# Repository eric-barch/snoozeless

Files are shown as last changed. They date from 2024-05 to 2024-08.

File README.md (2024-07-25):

# Snoozeless

Make yourself a morning person.

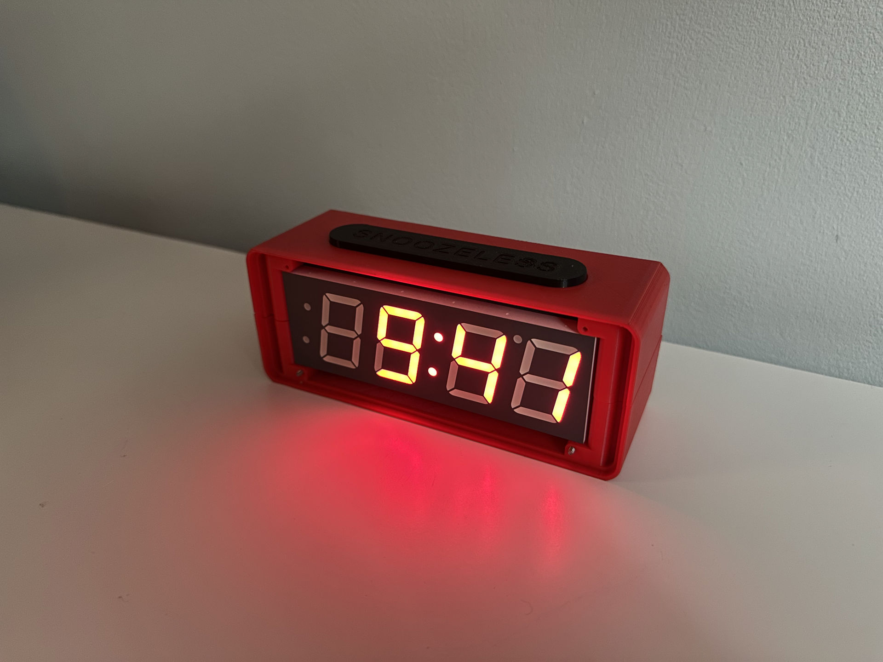
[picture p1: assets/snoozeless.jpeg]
The Snoozeless Alarm Clock


## The Problem

I’m a night owl by nature. Whether it’s genetic or a habit picked up in school, I’ve always had a tendency to wake up around 8 or 9 and fall asleep around 1 or 2.

On the rare occasion that I do wake up early (like, 6 or earlier), I always have a fantastic day. I've usually exercised, made breakfast, and gotten some work done by the time others are waking up. I feel like I have a head start on everyone else, setting the tone for a productive day.

Once I'm awake, I feel great, but the challenge is getting to that point. My discipline is at its absolute lowest at the moment my alarm sounds. No matter how good my intentions were when I set it the night before, and despite knowing logically that getting up is the right decision, I usually end up hitting snooze. And then hitting it again. And again. An embarassing number of 9-minute increments later, I finally get up around the time that I would have naturally, having accomplished nothing by setting an alarm other than decreasing the quality of my last hour of sleep.

I needed a way to change the incentives at the critical moment of decision, to make it more immediately expensive to stay in bed than to leave it.

## The Solution

The solution I landed on is an alarm clock that goes off not once, but twice. The first alarm functions like any regular alarm — it goes off, you wake up, and you turn it off. Turning off the first alarm, however, triggers a countdown to a second. The key difference is that the only way to cancel the countdown (or turn off the second alarm, if you've run out of time) is to physically reach a pre-determined geographic location (the gym, work, class, etc.). This design changes your incentives while you’re contemplating whether to get up. With the countdown ticking, every minute spent in bed reduces the time you have to reach your destination. You know that if the countdown reaches zero, the alarm will go off and you won’t be able to stop it.

Initially, I thought this could be a simple mobile app, but it’s actually impossible to implement on a device over which you don’t have full control of the hardware. If the alarm is going off on your phone, it can be turned off by simply quitting the app. This solution, then, requires a :sparkles:_distributed system_:sparkles:: an embedded device with full control over its noise-making peripherals to serve as the alarm clock, and a mobile app to confirm that you've reached your target location.

## Couldn't You Just...

### Unplug it?

No. There's a battery inside that's charging whenever it's plugged in. It can run for hours without wall power.

### Throw it across the room/move it to a different one?

No. There are screw holes under the snooze(less) bar that allow you to anchor the clock to something solid (e.g. your nightstand) if you really need to.

### Disconnect the internet?

No. Once the wakeup cycle begins, all logic runs onboard. All you accomplish by cutting the internet is to make it impossible to tell Snoozeless you've reached your destination. The second alarm will sound as scheduled until internet is restored and you've reached your destination.

### Turn it off via the server?

No. When the mobile app tells the server that you've reached your destination, it signs that message with a private key. Snoozeless validates the message with the corresponding public key. Even for me, with full access to the application's backend, it's cryptographically impossible to turn off an alarm by any method other than getting my phone to the correct geographic coordinates.

### Smash it with a hammer?

Yes. Yes, you could smash it with a hammer. I've put so much work into Snoozeless that I don't think some extra sleep would ever be worth that to me. If the tradeoff is different for you, the CAD files are [here](cad); I suggest machining it from steel.

## The Implementation

The pieces of the system are as follows:

### Database

Stores application state. Built with [Supabase](https://supabase.com/). There are only two tables, `devices` and `alarms`, plus the tables that Supabase generates automatically for auth and other concerns.

### Server

Handles routing and backend logic. Pre- and post-processes most of the database reads and writes. Implemented with [Hono](https://hono.dev/), which is pretty much just a modern, lightweight, TypeScript-first alternative to [Express](https://expressjs.com/). I've really enjoyed using it. Currently I just run the server locally on my machine, but plan to deploy it to the cloud in a Docker container running Node.

### Mobile Application

The need to know the user's location requires a mobile app. This one is built with [Flutter](https://flutter.dev/) and thus written in [Dart](https://dart.dev/).

### Embedded Application

Lastly, a standalone device needs a board and firmware. The [ESP32](https://www.espressif.com/en/products/socs/esp32) by Espressif is a very popular System on a Chip for Internet of Things applications. I have some experience programming these using the [Arduino](https://www.arduino.cc/) framework, but for this project I chose to use Espressif's own [ESP-IDF](https://github.com/espressif/esp-idf) for its lower-level control (and just to learn something new). The ESP-IDF libraries are written in C but fully support C++, which I took advantage of due to my proclivity for and/or addiction to object-oriented programming.

## Build One

I'm putting together a full build guide, but it's still a work in progress. Unfortunately, if you want to make your own, you're going to have to reverse engineer it from the resources in this repo. The CAD files are designed around these components from Adafruit:

- [Adafruit ESP32 Feather V2 - 8MB Flash + 2 MB PSRAM - STEMMA QT](https://www.adafruit.com/product/5400)
- [Breadboard-friendly 2.1mm DC barrel jack](https://www.adafruit.com/product/373)
- [Tactile Button switch (6mm) x 20 pack](https://www.adafruit.com/product/367)
- [Large Enclosed Piezo Element w/Wires](https://www.adafruit.com/product/1739)
- [Adafruit 7-Segment Backpack - 1.2" Tall Digits](https://www.adafruit.com/product/1271)
- [Red 7-segment clock display - 1.2" digit](https://www.adafruit.com/product/1264)

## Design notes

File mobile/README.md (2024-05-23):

# Snoozeless

Mobile app for the alarm clock that forces you to get out of bed in the morning.

## Use Case

Have you always wanted to be a morning person, but never been able to make it happen? What if your alarm clock absolutely **refused** to turn off until you got your lazy butt out of bed? Snoozeless _wakes_ you up like a normal alarm clock, but then forces you to actually _get_ up by threatening a second alarm if you don't physically move to a certain location within a time limit. A mobile app alone can't accomplish the task -- you could always override the alarm by simply quitting the app or turning off your phone. The product _needs_ to be a physical device with full control over its own audio output.

Snoozeless is a physical alarm clock accompanied by a mobile app. The clock is built around the [ESP32 System on a Chip](https://www.espressif.com/en/products/socs/esp32) and has a built-in rechargeable battery so you can't turn off the alarm by unplugging it.

## Setup

**Note:** The below is how Snoozeless used to work. It was never a commercial product, just something I used myself. The project is no longer developed or maintained.

1. Flash an ESP32 with the firmware and attach the necessary peripherals. Put it all in an enclosure. More detail at the [firmware repo](https://github.com/eric-barch/snoozeless-firmware).
2. Download the Snoozeless app, or clone this repo and install the app on your phone from your computer.
3. Create or sign in to an account in the app.
4. Pair the clock to your phone via Bluetooth.

## Daily Use

1. Before going to bed, open the app and configure the following settings for your clock:

- The time you want to be woken up initially
- The geographic destination you want to be forced to go to
- The amount of time you want to be given to get there

2. In the morning, you will be woken up at the initial time you set in step 1. You can turn off this first alarm by pressing the snooze bar on top of the clock.
3. Completing step 2 will start a countdown of the duration you set in step 1.
4. Bring your phone to the geographic location you set in step 1. Once your phone is close enough to the location, the countdown on your physical alarm clock will cancel. If the countdown has already elapsed and the alarm is sounding, it will turn off.
5. If you fail to get to your destination by the time the countdown ends, the second alarm will sound. There is no way to turn this alarm off other than by getting to the place you set in step 1. So hurry up! Get to work/gym/class/wherever!

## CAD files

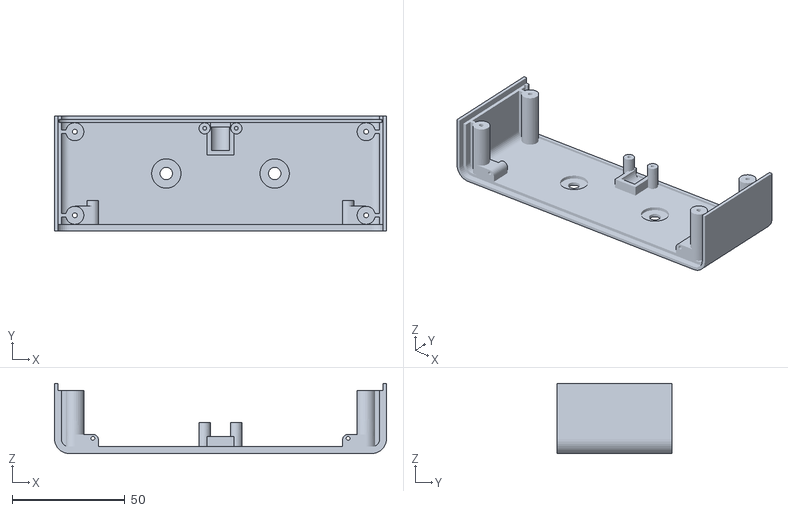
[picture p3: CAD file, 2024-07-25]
cad/snoozeless-bottom.stl
147.0 x 51.0 x 31.0

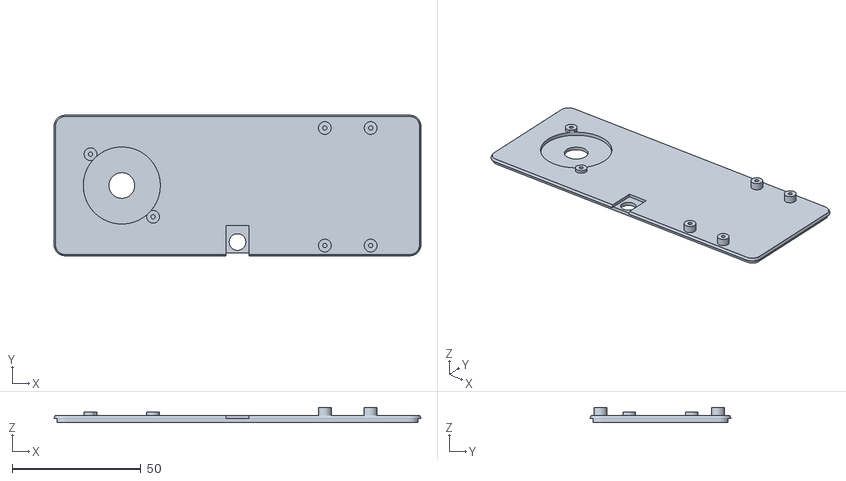
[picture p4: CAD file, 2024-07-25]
cad/snoozeless-back.stl
142.8 x 54.8 x 5.80

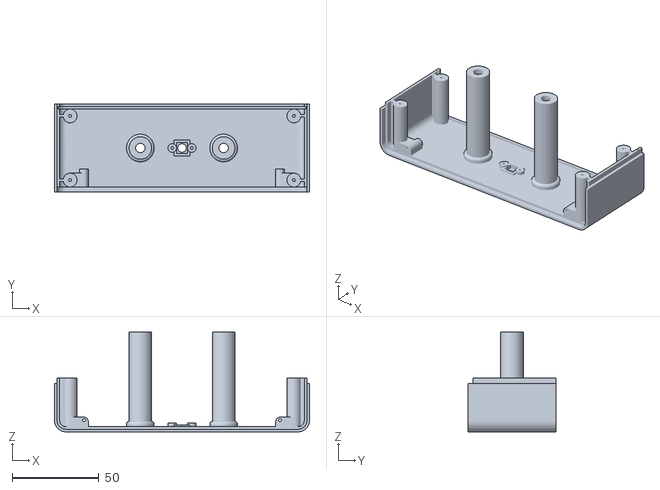
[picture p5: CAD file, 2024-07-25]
cad/snoozeless-top.stl
147.0 x 51.0 x 57.5

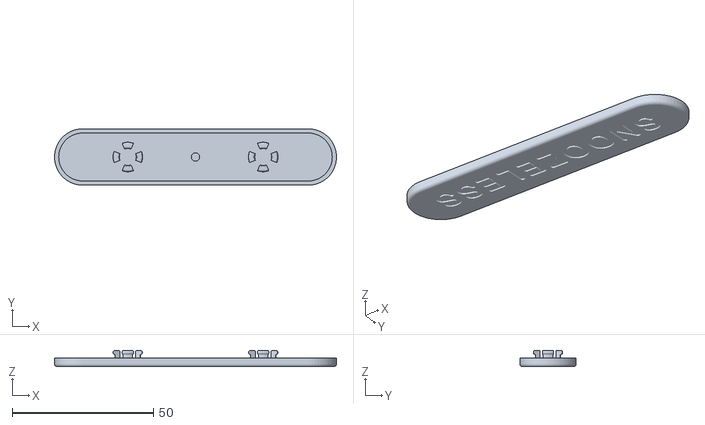
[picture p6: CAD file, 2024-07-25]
cad/snoozeless-bar.stl
100.0 x 20.0 x 5.81

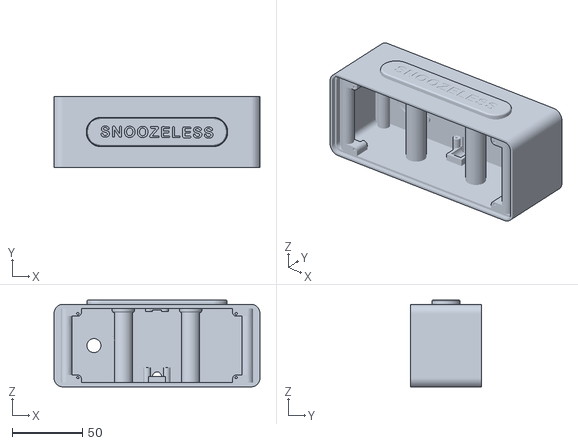
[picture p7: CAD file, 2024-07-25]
cad/snoozeless.stl
147.0 x 51.0 x 62.0

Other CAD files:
cad/snoozeless.f3d

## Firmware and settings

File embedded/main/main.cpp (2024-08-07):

#include "Alarms.h"
#include "Button.h"
#include "Buzzer.h"
#include "CurrentTime.h"
#include "Device.h"
#include "Display.h"
#include "NonVolatileStorage.h"
#include "Session.h"
#include "StateMachine.h"
#include "StateStream.h"
#include "WifiConnection.h"
#include <freertos/idf_additions.h>

extern "C" void app_main(void) {
  /**ESP system utilities. */
  NonVolatileStorage non_volatile_storage;
  WifiConnection wifi_connection(non_volatile_storage);

  /**Auth. */
  Session session(non_volatile_storage);

  /**State. */
  Device device(non_volatile_storage);
  Alarms alarms(non_volatile_storage);

  /**Realtime state updates from backend. */
  StateStream state_stream(session, device, alarms);

  /**UNIX time. */
  CurrentTime current_time(non_volatile_storage, session);

  /**Peripherals. */
  Button button;
  Buzzer buzzer;
  Display display(device, current_time);

  /**Orchestrate processes. */
  StateMachine state_machine(device, alarms, current_time, button, display,
                             buzzer);

  vTaskDelay(portMAX_DELAY);
}

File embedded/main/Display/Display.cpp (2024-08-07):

#include "Display.h"
#include "CurrentTime.h"
#include "Device.h"
#include "NonVolatileStorage.h"
#include <cstring>
#include <ctime>
#include <esp_log.h>
#include <freertos/idf_additions.h>
#include <ht16k33.h>
#include <i2cdev.h>
#include <regex>
#include <string>

Display::Display(Device &device, CurrentTime &current_time)
    : device(device), current_time(current_time), ht16k33(), ht16k33_ram(0),
      top_indicator(false), bottom_indicator(false), colon(false),
      apostrophe(false), major_interval(), minor_interval() {
  /**Initialize display structs. */
  memset(&ht16k33, 0, sizeof(i2c_dev_t));
  memset(&ht16k33_ram, 0, sizeof(ht16k33_ram));

  /**I2C communication pin definitions. */
  gpio_num_t sda = static_cast<gpio_num_t>(CONFIG_I2C_MASTER_SDA);
  gpio_num_t scl = static_cast<gpio_num_t>(CONFIG_I2C_MASTER_SCL);
  i2c_port_t port = static_cast<i2c_port_t>(0);

  /**Configure GPIO2 (I2C power) and set high.
   * https://learn.adafruit.com/adafruit-esp32-feather-v2/pinouts#stemma-qt-connector-3112257
   */
  gpio_config_t io_conf;
  io_conf.intr_type = GPIO_INTR_DISABLE;
  io_conf.mode = GPIO_MODE_OUTPUT;
  io_conf.pin_bit_mask = (1ULL << GPIO_NUM_2);
  gpio_config(&io_conf);
  gpio_set_level(GPIO_NUM_2, 1);

  /**Initialize I2C and ht16k33 display drivers. */
  ESP_ERROR_CHECK(i2cdev_init());
  ESP_ERROR_CHECK(
      ht16k33_init_desc(&ht16k33, port, sda, scl, HT16K33_DEFAULT_ADDR));
  ESP_ERROR_CHECK(ht16k33_init(&ht16k33));
  ESP_ERROR_CHECK(ht16k33_display_setup(&ht16k33, 1, HTK16K33_F_0HZ));
}

Display::~Display() {
  memset(&ht16k33, 0, sizeof(i2c_dev_t));
  ht16k33_free_desc(&ht16k33);
  ESP_LOGI(TAG, "Destroy.");
}

void Display::print_9_41() {
  set_major_interval(std::string("9"));
  colon = true;
  set_minor_interval(std::string("41"));
  bottom_indicator = false;
  print();
}

void Display::print_current_time() {
  std::string hour_format, minute_format, pm_format;
  std::smatch match;

  const std::regex specifier_regex("%[a-zA-Z]");
  const std::regex colon_regex(":");
  const std::regex pm_regex("%p");

  std::string time_format = device.get_time_format();
  std::tm time = current_time.get_time();

  /**Find hour format specifier. */
  if (std::regex_search(time_format, match, specifier_regex)) {
    hour_format = match.str();
    time_format = match.suffix();
  }

  /**Check for colon. */
  if (std::regex_search(time_format, match, colon_regex)) {
    colon = true;
    time_format = match.suffix();
  } else {
    colon = false;
  }

  /**Find minute format specifier. */
  if (std::regex_search(time_format, match, specifier_regex)) {
    minute_format = match.str();
    time_format = match.suffix();
  }

  /**Check for PM indicator. */
  pm_format.clear();
  if (std::regex_search(time_format, match, pm_regex)) {
    pm_format = match.str();
    time_format = match.suffix();
  }

  char buffer[10];

  /**Set major interval. */
  if (!hour_format.empty()) {
    strftime(buffer, sizeof(buffer), hour_format.c_str(), &time);
    set_major_interval(buffer);
  }

  /**Set minor interval. */
  if (!minute_format.empty()) {
    strftime(buffer, sizeof(buffer), minute_format.c_str(), &time);
    set_minor_interval(buffer);
  }

  /**Set bottom_indicator. */
  if (!pm_format.empty()) {
    strftime(buffer, sizeof(buffer), pm_format.c_str(), &time);
    bottom_indicator = (std::string(buffer) == "PM");
  } else {
    bottom_indicator = false;
  }

  print();
}

void Display::print_countdown(Countdown &countdown) {}

const char *const Display::TAG = "display";

const std::map<const char, const uint8_t> Display::alphabet = {
    {'0', 0x3F}, {'1', 0x06}, {'2', 0x5B}, {'3', 0x4F}, {'4', 0x66},
    {'5', 0x6D}, {'6', 0x7D}, {'7', 0x07}, {'8', 0x7F}, {'9', 0x6F},
    {' ', 0x00}, {'A', 0x77}, {'B', 0x7C}, {'C', 0x39}, {'D', 0x5E},
    {'E', 0x79}, {'F', 0x71}, {'G', 0x3D}, {'H', 0x76}, {'I', 0x30},
    {'J', 0x1E}, {'K', 0x75}, {'L', 0x38}, {'M', 0x15}, {'N', 0x37},
    {'O', 0x3F}, {'P', 0x73}, {'Q', 0x6B}, {'R', 0x33}, {'S', 0x6D},
    {'T', 0x78}, {'U', 0x3E}, {'V', 0x3E}, {'W', 0x2A}, {'X', 0x76},
    {'Y', 0x6E}, {'Z', 0x5B},
};

void Display::set_major_interval(const std::string &major_interval) {
  int length = major_interval.length();
  if (length < 1 || length > 2) {
    ESP_LOGE(TAG,
             "Did not set major interval. Must be one or two characters long.");
    return;
  }
  this->major_interval = major_interval;
}

void Display::set_minor_interval(const std::string &minor_interval) {
  int length = minor_interval.length();
  if (length < 1 || length > 2) {
    ESP_LOGE(TAG,
             "Did not set minor interval. Must be one or two characters long.");
    return;
  }
  this->minor_interval = minor_interval;
}

void Display::set_brightness(uint8_t brightness) {
  uint8_t cmd = 0xE0 | brightness;
  esp_err_t err = i2c_master_write_to_device(I2C_NUM_0, ht16k33.addr, &cmd, 1,
                                             1000 / portTICK_PERIOD_MS);
  if (err != ESP_OK) {
    ESP_LOGE(TAG, "Error setting brightness: %s", esp_err_to_name(err));
  }
}

void Display::print() {
  memset(ht16k33_ram, 0, sizeof(ht16k33_ram));

  set_brightness(device.get_brightness());

  if (major_interval.length() > 0) {
    if (major_interval[1] == '\0') {
      ht16k33_ram[0] = alphabet.at(' ');
      ht16k33_ram[2] = alphabet.at(major_interval[0]);
    } else {
      ht16k33_ram[0] = alphabet.at(major_interval[0]);
      ht16k33_ram[2] = alphabet.at(major_interval[1]);
    }
  }

  if (minor_interval.length() > 0) {
    if (minor_interval[1] == '\0') {
      ht16k33_ram[6] = alphabet.at(' ');
      ht16k33_ram[8] = alphabet.at(minor_interval[0]);
    } else {
      ht16k33_ram[6] = alphabet.at(minor_interval[0]);
      ht16k33_ram[8] = alphabet.at(minor_interval[1]);
    }
  }

  uint8_t indicators = 0b00000;

  /**Indicators are set by these bits:
   * 0b00000
   *   ││││└─ no effect
   *   │││└── colon
   *   ││└─── top_indicator
   *   │└──── bottom_indicator
   *   └───── apostrophe */

  if (apostrophe) {
    indicators += 0b10000;
  }
  if (bottom_indicator) {
    indicators += 0b01000;
  }
  if (top_indicator) {
    indicators += 0b00100;
  }
  if (colon) {
    indicators += 0b00010;
  }

  ht16k33_ram[4] = indicators;

  ESP_ERROR_CHECK(ht16k33_ram_write(&ht16k33, ht16k33_ram));
}

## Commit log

2022-02-26 Finalize first draft of Edit Device form and supporting changes.
2022-02-26 Add Delete Device capability.
2022-02-27 Added Add Device capability.
2022-03-06 Added sortBy createdAt for both devices list and alarms list.
2024-05-31 feat(server): Server sends device state changes as SSE stream
2024-06-01 feat(server): Implement auth on GET /device/state endpoint
2024-06-01 feat(server): Implement register device endpoint
2024-06-02 fix(server): Register device endpoint requires user_id _and_ session_id
2024-06-02 feat(server): Implement unregister device endpoint
2024-06-02 refactor(server): Clarify naming of register device service arguments
2024-06-02 fix(server): Get device state endpoint accepts deviceId argument
2024-06-02 feat(server): Implement update device endpoint
2024-06-07 fix(server): deviceId is passed to get device state endpoint in query rather than body
2024-06-13 feat(embedded): Subscribes to SSE device state stream with auth
2024-06-19 feat(embedded): Device ID is retrieved from global state instead of ESP-IDF config
2024-06-20 refactor(server): Register device endpoint uses Supabase client from auth middleware
2024-06-20 feat(embedded): Register device endpoint JSON response is parsed into device state
2024-06-20 fix(embedded): Subscribe to device service calls get device state controller
2024-06-20 fix(server): Fix device state stream typo
2024-06-20 refactor(server): Remove unregister device endpoint
2024-06-21 feat(embedded): Implement getters and setters for device state properties
2024-06-21 feat(embedded): Parse device state stream and write to onboard state
2024-06-21 refactor(embedded): Refactor device state
2024-06-21 refactor(embedded): Put all device state services in one file
2024-06-21 refactor(embedded): Refactor POST device/register controller
2024-06-23 feat(embedded): Implement device state int setters and getters
2024-06-23 feat(embedded): Initializing device sets device state integers
2024-06-23 feat(embedded): Device state stream updates write to onboard device state ints
2024-06-24 feat: GET device/state sends initial state at beginning of stream
2024-06-24 refactor(embedded): Rename device_t to device_state_t
2024-06-24 fix(embedded): Handle unknown device state event type
2024-06-24 style(embedded): Rename GET device state controller variables
2024-06-25 fix(embedded): Align Unix calibration with ESP log messages
2024-06-29 refactor(embedded): Make calibrate_real_time static
2024-07-03 feat(embedded): Implement Device
2024-07-05 feat(embedded): ApiRequest.call runs as separate thread via freeRTOS
2024-07-05 refactor(embedded): Refactor `Device` to match `Session` style and structure
2024-07-05 style(embedded): Improve Device log messages
2024-07-09 feat(embedded): `Device` calls `ApiRequest` on separate thread
2024-07-09 fix(server): `device/register` returns single JSON object instead of array
2024-07-09 feat(embedded): `Device` sets its `id` on enroll
2024-07-09 feat(embedded): Working preliminary implementation of `CurrentTime`
2024-07-09 refactor(embedded): `Device` takes `CurrentTime` as dependency
2024-07-09 feat(embedded): `CurrentTime` calibrates itself via API on init
2024-07-09 refactor(CurrentTime): Add getters and setters
2024-07-09 refactor(Device): Add setter
2024-07-09 style(server): Fix device route imports
2024-07-09 fix: `/auth/refresh` returns snake case
2024-07-09 feat(embedded): Enrolling `Device` sets `utc_offset` and `format` properties on `CurrentTime`
2024-07-10 fix(embedded): `ApiRequest` event handler prints output buffer on auth error
2024-07-10 feat(embedded): Enrolling `Device` sets `Display.brightness`
2024-07-13 feat(embedded): Display shows current Unix time
2024-07-13 feat(embedded): `CurrentTime` accounts for time zone
2024-07-13 fix(embedded): `Display` gets brightness from NVS on startup
    [Display.cpp]
2024-07-16 fix(embedded): `CurrentTime` blocks itself for synchronous API calls
    [main.cpp]
2024-07-16 fix(embedded): `Device` blocks itself for synchronous API requests
2024-07-16 fix(embedded): Make `Display` compatible with Feather HUZZAH32 v2
    [Display.cpp]
2024-07-16 fix(server): Remove extraneous info from GET device/state response
2024-07-16 feat(embedded): `Device` subscribes to state 🎉
2024-07-16 fix(server): Change `/device/register` endpoint to `/device/enroll`
2024-07-16 refactor(embedded): `Device` subscribes itself to state updates
2024-07-18 feat(embedded): `Session` handles failed refresh
    [main.cpp]
2024-07-18 feat(embedded): `CurrentTime` handles failed calibration
    [main.cpp]
2024-07-18 feat(embedded): `Device` handles failed subscription
    [main.cpp]
2024-07-19 feat(embedded): Preliminary implementation of `Buzzer`
    [Buzzer.cpp, main.cpp]
2024-07-19 feat(server): `/device/state/` SSE stream includes alarm updates
2024-07-21 feat(server): GET `/device/state` endpoint sends alarm updates
2024-07-21 fix(embedded): Remove unnecessary loop in `main`
    [main.cpp]
2024-07-24 fix(embedded): Prevent `Display` power crash on first boot
    [Display.cpp]
2024-07-24 refactor(embedded): `Device` manages all of its members
2024-07-24 fix(embedded): Fix clangd LSP for nvim
    [Buzzer.cpp, Display.cpp]
2024-07-24 fix(embedded): Fix stack overflow in `CurrentTime.keep_calibrated`
2024-07-24 fix(server): GET `/device/state` endpoint sends event label for keep-alive
2024-07-24 feat(server): Implement POST `/device/alarm` endpoint
2024-07-24 feat(embedded): `Device` handles initial alarms
2024-07-24 fix(embedded): `CurrentTime` reads NVS calibration from correct key
2024-07-25 feat(cad): Add CAD files
    [snoozeless-back.stl, snoozeless-bar.stl, snoozeless-bottom.stl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]
2024-07-26 feat(embedded): Implement `Display.print_9_41()`
2024-07-26 feat(embedded): `Alarms` are initialized from NVS and then `Device` SSE stream
2024-07-29 refactor(embedded): Refactor `CurrentTime`
2024-07-29 refactor(embedded): Refactor `Device`
2024-07-29 fix(server): POST `/device/enroll` service endpoint return type is implicit
2024-07-29 refactor(embedded): Reduce duplication in `Device`
2024-07-29 fix(embedded): `CurrentTime` properties get default values
2024-07-29 fix(embedded): Add various error guards to `Display`
    [Display.cpp]
2024-07-30 fix(embedded): Fix `Display` crash on initial startup
    [Display.cpp]
2024-07-31 refactor(embedded): Move persistent API connection logic from `Device` to `StateStream`
2024-08-01 feat(embedded): Preliminary implementation of `Device` state machine
2024-08-07 feat(embedded): Preliminary implementation of `Button`
